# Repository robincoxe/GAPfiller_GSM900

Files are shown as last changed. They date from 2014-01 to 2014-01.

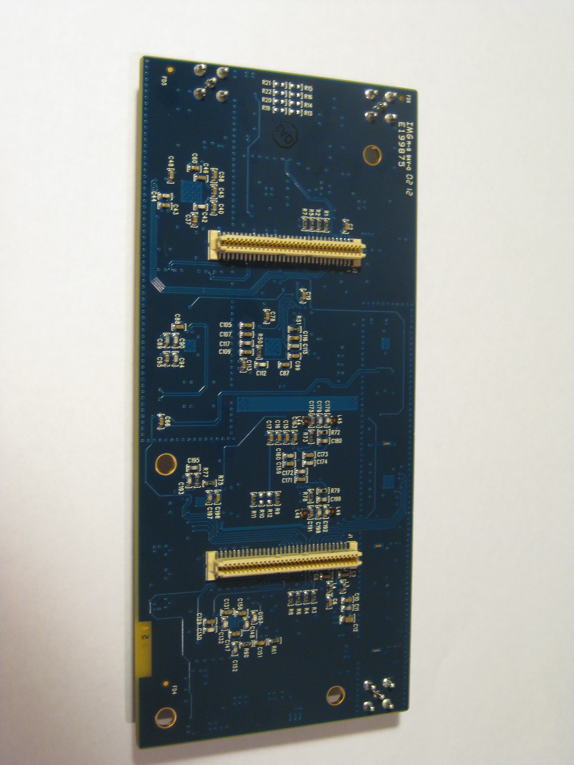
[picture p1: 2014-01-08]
docs/GAPfiller_GSM900_bottom.jpg

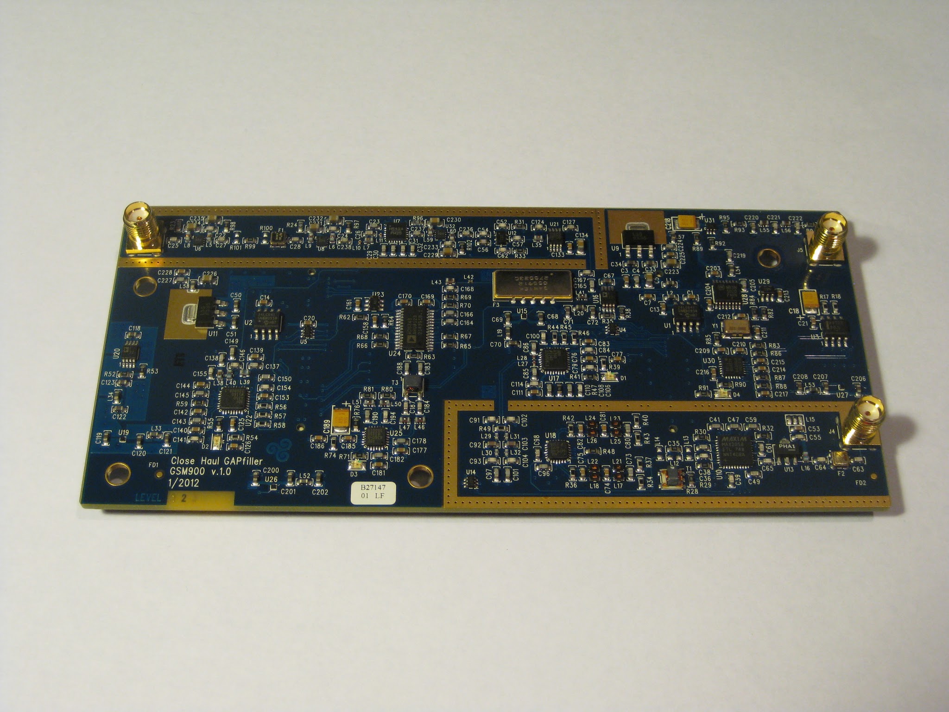
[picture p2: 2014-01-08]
docs/GAPfiller_GSM900_top.jpg

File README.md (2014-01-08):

# GAPfiller GSM900 Version 3 #

Copyright 2014, Close-Haul Communications, Inc.

### Revision History ###

7 January 2014: First commit of OrCAD schematics, PADS PCB layout, Gerber files

### README ###

The GAPfiller GSM900 version 3.0 board is a RF front end daughtercard intended for a single TRX GSM basestation in the 900 MHz band.  The GAPfiller GSM900 is compatible with the [Ettus Research](https://www.ettus.com/product) USRP software-defined radio systems. 

Modifications to the USRP FPGA and UHD are necessary to run OpenBTS or osmo-bts on the GAPfiller board.  As this work is completed, these modifications will be added to this repository on Github.
 
This design is open source hardware released under the [CERN Open Hardware Licence v1.2](http://www.ohwr.org/licenses/cern-ohl/v1.2).

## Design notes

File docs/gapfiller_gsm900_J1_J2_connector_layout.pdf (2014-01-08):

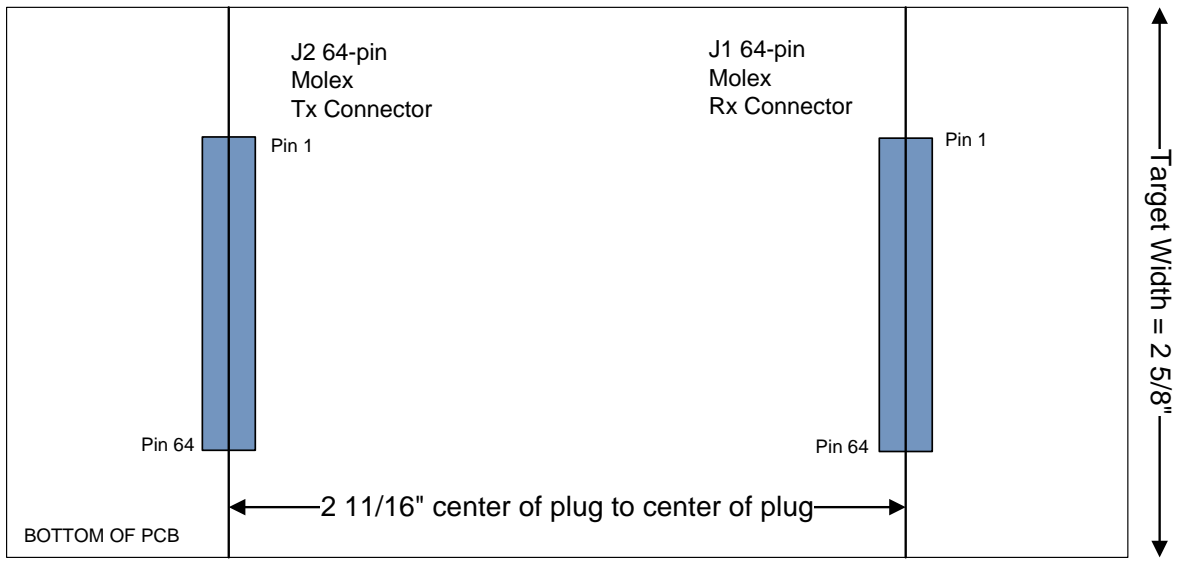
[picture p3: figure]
BOTTOM OF PCB; J2 64-pin Molex Tx Connector; J1 64-pin Molex Rx Connector; Pin 1; Target Width = 2 5/8"; Pin 64

GAPfiller GSM900
Daughterboard Connector Layout Close-Haul Communications, Inc.
October 2011

Copyright 2011 Close-Haul Communications, Inc. All Rights Reserved

NOT TO SCALE!

2 11/16" center of plug to center of plug

Target Length = 5 ¾”

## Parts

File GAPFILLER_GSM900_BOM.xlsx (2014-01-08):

 |  | Close-Haul Communications Inc. GAPfiller_GSM900 Revision: 2
 |  | Bill Of Materials 7 Feb 2013
Item # | Quantity | Reference | Part | Footprint | Description | Manufacturer | Mfg. Part # | Vendor | Customer Supplied Qty.
1 | 66 | C1,C2,C3,C6,C7,C8,C9,C10,C13,C14,C15,C16,C17,C19,C20, C21,C40,C43,C45,C48,C53,C58,C66,C78,C83,C87,C88,C95, C99,C105,C107,C109,C111,C113,C129,C131,C139, C140,C142,C144,C147,C153,C156,C158,C159,C161,C163, C169,C170,C171,C173,C177,C181,C196,C203,C209,C210, C211,C212,C213,C214,C215,C216,C217,C225,C228 | 0.1 uF | IPC_0603 | CAP CERAMIC 0603 X7R .1UF 10% 50V | Cal-Chip | GMC10X7R104K50NT-LF | Cal-Chip
2 | 26 | C4,C11,C23,C41,C47,C59,C89,C96,C97,C101,C108,C110, C143,C145,C164,C166,C178,C182,C183,C188,C190,C197, C205,C219,C224,C227 | 1 nF | IPC_0603 | CAP CER 1000PF 5% 50V NP0 0603 | AVX | 06035A102JAT2A | Digikey
3 | 11 | C5,C12, C134, C223,C226,C229,C230,C231,C232,C234,C235 | 4.7 uF | IPC_0805 | CAP CER 4.7UF 16V X5R 0805 | Murata | GRM21BR61C475KA88L | Digikey
4 | 3 | C18,C189,C218 | 10 uF | IPC_1210 | CAP TANTALUM 10UF 16V 10% SMD | Kemet | B45190E3106K209 | Digikey
5 | 21 | C36,C39,C42,C54,C57,C63,C64,C65,C79,C84,C100,C106, C112,C114,C130,C132,C141,C148,C154,C157,C168 | 47 pF | IPC_0603 | CAP0603 COG 47PF 5% 50V | Kemet | IPC_0603C470J5GACTU | Newark
6 | 1 | C26 | 8 pF | IPC_0603 | CAP0603 COG 8 PF 0.5PF 50V | Multicomp | MIPC_0603N8R0D500CT | Newark
7 | 25 | C25,C27,C28,C29,C30,C31,C32,C38,C44,C49,C61,C90,C94, C98,C127,C160,C172,C174,C184,C187,C236,C237,C238, C239,C240 | 100 pF | IPC_0603 | CAP0603 COG 100PF 5% 50V | AVX | 06035A101JAT2A | Newark
8 | 22 | C33,C34,C50,C51,C67,C68,C69,C70,C71,C72,C118,C119, C120,C121,C122,C123,C200,C201,C202,C206,C207,C208 | 1 uF | IPC_0603 | CAP CERAMIC 1.00UF 16V X5R 0603 | Kemet | IPC_0603C105K4PACTU | Digikey
9 | 9 | C35,R83,R85,R86,R87,R88,R94,R99,R103 | 0 | IPC_0603 | RES 0.0 1/10W 5% 0603 | Vishay | CRCW06030000Z0EA | Arrow
10 | 10 | C37,C60,C76,C77,C125,C126,C133,C185,C186,C204 | 0.01 uF | IPC_0603 | CAP CER 10000PF 50V X7R 0603 | Kemet | IPC_0603C103J5RACTU | Digikey
11 | 1 | C46 | 3.9 pF | IPC_0603 | CAP0603 COG 4PF 5% 50V | TDK | C1608C0G1H040B | Newark
12 | 3 | C52,C55,C62 | 22 pF | IPC_0603 | CAP0603 COG 22PF 5% 50V | Kemet | IPC_0603C220J5GACTU | Newark
13 | 1 | C56 | 150 pF | IPC_0603 | CAP0603 COG 150PF 5% 50V | AVX | 06035A151JAT2A | Newark
14 | 2 | C73,C80 | 1.4 nF | IPC_0603 | CAP0603 COG 1500PF 5% 50V | TDK | C1608C0G1H152J | Newark
15 | 2 | C74,C81 | 6.4 nF | IPC_0603 | CAP0603 X7R 6800PF 10% 50V | Kemet | IPC_0603C682K5RACTU | Newark
16 | 2 | C75,C82 | 18 nF | IPC_0603 | CAP CER 0603 0.018UF 25V X7R | Multicomp | MIPC_0603B183K250CT | Newark
17 | 5 | C85,C86,C137,C138,C221 | 120 pF | IPC_0603 | CAP CER 120PF 50V 5% C0G 0603 | AVX | 06035A121JAT2A | Newark
18 | 5 | C91,C93,C102,C104,C124 | 3.3 pF | IPC_0603 | CAP0603 COG 3.3PF 5% 50V | Multicomp | MC0603N3R3C210CT | Newark
19 | 2 | C92,C103 | 4.7 pF | IPC_0603 | CAP0603 COG 4.7PF 5% 50V | Multicomp | MC0603N4R7C210CT | Newark
20 | 2 | C115,C150 | 2700 pF | IPC_0603 | CAP CER 2700PF 50V C0G 0603 | Murata | GRM1885C1H272JA01D | Digikey
21 | 2 | C116,C151 | 39 nF | IPC_0603 | CAP CER X7R 0.039UF 10% 16V 0603 | Multicomp | MIPC_0603B393K160CT | Newark
22 | 2 | C117,C152 | 1200 pF | IPC_0603 | CAP CER 1200PF 50V 5% C0G 0603 | Murata | GRM1885C1H122JA01D | Digikey
23 | 2 | C146,C155 | 2.2 pF | IPC_0603 | CAP0603 COG 2.2PF 5% 50V | Multicomp | MC0603N2R2C210CT | Cal-Chip
24 | 1 | C149 | 10 pF | IPC_0603 | CAP0603 COG 10PF 5% 50V | Cal-Chip | GMC10CG100J50NT-LF | Cal-Chip
25 | 1 | C165 | 7 pF | IPC_0603 | CAP0604 COG 7PF 5% 50V | Multicomp | MC0603N7R0C210CT | Newark
26 | 4 | C22,C24,C167,C233 | 33 pF | IPC_0603 | CAP0603 COG 33PF 5% 50V | Cal-Chip | GMC10CG330J50NT-LF | Cal-Chip
27 | 3 | C175,C191 | 8.2 pF | IPC_0603 | CAP0603 COG 8.2PF 5% 50V | Cal-Chip | GMC10CG8R2J50NT-LF | Cal-Chip
28 | 2 | C176,C192 | 14.2 pF | IPC_0603 | CAP0603 COG 15PF 5% 50V | AVX | 06035A150JAT2A | Newark
29 | 2 | C179,C198 | 260 pF | IPC_0603 | CAP0603 COG 270PF 5% 50V | AVX | 06035A271JAT2A | Newark
30 | 2 | C180,C199 | 142 pF | IPC_0603 | CAP0603 COG 150PF 5% 50V | AVX | 06035A151JAT2A | Newark
31 | 1 | C193 | 122 pF | IPC_0603 | CAP0603 COC 120PF 5% 50V | AVX | 06035A121JAT2A | Newark
32 | 1 | C194 | 56 pF | IPC_0603 | CAP0603 COG 56PF 5% 50V | Cal-Chip | GMC10CG560J50NT-LF | Cal-Chip
33 | 1 | C195 | 1.6 nF | IPC_0603 | CAP CER 1600PF 50V 5% C0G 0603 | Murata | GRM1885C1H162JA01D | Digikey
34 | 1 | C220 | 68 pF | IPC_0603 | CAP0603 COG 68PF 5% 50V | Cal-Chip | GMC10CG680J50NT-LF | Cal-Chip
35 | 1 | C222 | 82 pF | IPC_0603 | CAP0603 COG 82PF 5% 50V | Cal-Chip | GMC10CG820J50NT-LF | Cal-Chip
36 | 1 | D1,D2,D3,D4 | GREEN_LED | IPC_0805 | LED GREEN CLEAR THIN 0805 SMD | Lite-On | LTST-C171GKT | Digikey
37 | 1 | F1 | 856671 | SM3x3x1p22mm | 897.5 MHz SAW Filter | Triquint | 856671 | Verical
38 | 1 | F2 | 855810 | SM3x3x1p22mm | 942.5 MHz SAW Filter | Triquint | 855810 | Verical | 50 (please return excess)
39 | 1 | F3 | 856347 | 855912 | 170.6 MHz GSM IF SAW filter | Triquint | 856347 | Verical | 50 (please return excess)
40 | 2 | J1,J2 | 71439-0164 | 64PIN_71439 | Molex 64 pin plug connectors | Molex | 71439-0164 | Digikey
41 | 3 | J3,J4,J5 | SMA-SMD | SMA-SMD | SMA connector, straight PCB | Amphenol | 901-144-8RFX | Digikey
42 | 7 | L1,L3,L20,L34,L54,L57,L58 | ferrite_0603 1000ma | IPC_0603 | FERRITE CHIP POWER 1000 mA 600 OHM SMD | Steward | MI0603J601R-10 | Digikey
43 | 6 | L2,L4,L19,L33,L52,L53 | ferrite_0603 200ma | IPC_0603 | FERRITE 200MA 1000 OHM 0603 SMD | Steward | HZ0603B102R-10 | Digikey
44 | 2 | L7,L35 | 10 nH | IPC_0603 | IND0603CS 10NH | Coilcraft | 0603CS-10NXJLU | Coilcraft
45 | 2 | L10,L11 | 7 nH | IPC_0302 | IND0302CS 7NH | Coilcraft | 0302CS-7N0XJLU | Coilcraft
46 | 5 | L12,L13,L14,R100,R101 | DNI | IPC_0603
47 | 1 | L15 | NFM21P | IPC_0805 | FILTER LC HIGH FREQ .47UF 0805 | Murata | NFM21PC474R1C3D | Digikey
48 | 1 | L16 | 18 nH | IPC_0603 | IND0603CS 18NH | Coilcraft | 0603CS-18NXJLU | Coilcraft
49 | 6 | L5,L6,L8,L9,L59,L60 | 33 nh | IPC_0603 | IND0603CS 33NH | Coilcraft | 0603CS-33NXJLU | Coilcraft
50 | 4 | L17,L21,L23,L25 | 10 uH | IPC_0603 | IND0603LS 10UH | Coilcraft | 0603LS-103XJLU | Coilcraft
51 | 4 | L18,L22,L24,L26 | 22 uH | IPC_0603 | IND0603LS 22UH | Coilcraft | 0603LS-223XJLU | Coilcraft
52 | 2 | L27,L28 | 19 nH | IPC_0302 | IND0302CS 19NH | Coilcraft | 0302CS-19NXJLU | Coilcraft
53 | 4 | L29,L30,L31,L32 | 2.7 nH | IPC_0402 | IND0402CS 2.7NH | Coilcraft | 0402CS-2N7XJLU | Coilcraft
54 | 1 | L38 | 39 nH | IPC_0603 | IND0603CS 39NH | Coilcraft | 0603CS-39NXJLU | Coilcraft
55 | 2 | L39,L40 | 12 nH | IPC_0603 | IND0603CS 12NH | Coilcraft | 0603CS-12NXJLU | Coilcraft
56 | 1 | L41 | 150 nH | IPC_0603 | IND0603HP 150NH | Coilcraft | 0603HP-R15XJLU | Coilcraft
57 | 1 | L42 | 4 nH | IPC_0302 | IND0302CS 4NH | Coilcraft | 0302CS-4N0XJLU | Coilcraft
58 | 1 | L43 | 47 nH | IPC_0603 | IND0603CS 47NH | Coilcraft | 0603CS-47NXJLU | Coilcraft
59 | 2 | L44,L48 | 1.2 uH | IPC_0603 | IND0603LS 1.2UH | Coilcraft | 0603LS-122XJLU | Coilcraft
60 | 2 | L45,L49 | 2.1 uH | IPC_0603 | IND0603LS 2.2UH | Coilcraft | 0603LS-222XJLU | Coilcraft
61 | 2 | L46,L47 | 148 nH | IPC_0603 | IND0603HP 150NH | Coilcraft | 0603HP-R15XJLU | Coilcraft
62 | 2 | L50,L51 | 94.7 nH | IPC_0603 | IND0603HP 91NH | Coilcraft | 0603HP-91NXJLU | Coilcraft
63 | 2 | L55,L56 | 220 nH | IPC_0603 | IND0603HP 220NH | Coilcraft | 0603HP-R22XJLU | Coilcraft
64 | 12 | R1,R2,R3,R4,R5,R6,R7,R8,R31,R33,R48,R91 | 330 | IPC_0603 | RES 330 1/10W 5% 0603 | Vishay/Dale | CRCW0603330RFKEA | Arrow
65 | 2 | R9,R11 | 2.49K | IPC_0603 | RES 2.49K 1/10W 5% 0603 | Vishay/Dale | CRCW06032K49FKEA | Arrow
66 | 10 | R10,R12,R13,R14,R15,R16,R19,R20,R21,R22 | DNI | IPC_0603
67 | 2 | R17,R18 | 33 | IPC_0603 | RES 33 1/10W 5% 0603 | Vishay/Dale | CRCW060333R0FKEA | Arrow
68 | 1 | R28 | 110 | IPC_0603 | RES 110 1/10W 5% 0603 | Vishay/Dale | CRCW0603110RFKEA | Arrow
69 | 2 | R29,R62 | 2K | IPC_0603 | RES 2K 1/10W 5% 0603 | Vishay/Dale | CRCW06032K00FKEA | Arrow
70 | 1 | R30 | 1.2K | IPC_0603 | RES 1.2K 1/10W 5% 0603 | Vishay/Dale | CRCW06031K20FKEA | Arrow
71 | 1 | R32 | 3.92K | IPC_0603 | RES 3.92K 1/10W 5% 0603 | Vishay/Dale | CRCW06033K92FKEA | Arrow
72 | 3 | R23,R24,R96 | 6.8K | IPC_0603 | RES 6.8K 1/10W 5% 0603 | Vishay/Dale | CRCW06068K92FKEA
73 | 3 | R97,R98,R102 | 8.2 | IPC_0603 | RES 8.2 1/10W 5% 0603 | Vishay/Dale | CRCW060308R0FKEA
74 | 7 | R34,R37,R39,R40,R43,R54,R74 | 49.9 | IPC_0603 | RES 49.9 1/10W 5% 0603 | Vishay/Dale | CRCW060349R9FKEA | Arrow
75 | 2 | R35,R52 | 210K | IPC_0603 | RES 210K 1/10W 5% 0603 | Vishay/Dale | CRCW0603210KFKEA | Arrow
76 | 5 | R36,R42,R49,R72,R79 | 100 | IPC_0603 | RES 100 1/10W 5% 0603 | Vishay/Dale | CRCW0603100RFKEA | Arrow
77 | 2 | R38,R53 | 64.9K | IPC_0603 | RES 64.9K 1/10W 5% 0603 | Vishay/Dale | CRCW060364K9FKEA | Arrow
78 | 6 | R41,R55,R71,R82,R84,R90 | 1K | IPC_0603 | RES 1K 1/10W 5% 0603 | Vishay/Dale | CRCW06031K00FKEA | Arrow
79 | 6 | R44,R45,R46,R56,R57,R58 | 10K | IPC_0603 | RES 10K 1/10W 5% 0603 | Vishay/Dale | CRCW060310K0FKEA | Arrow
80 | 4 | R47,R59,R76,R95 | 4.7K | IPC_0603 | RES 4.7K 1/10W 5% 0603 | Vishay/Dale | CRCW06034K70FKEA | Arrow
81 | 2 | R50,R60 | 680 | IPC_0603 | RES 680 1/10W 5% 0603 | Vishay/Dale | CRCW0603680RFKEA | Arrow
82 | 2 | R51,R61 | 360 | IPC_0603 | RES 360 1/10W 5% 0603 | Vishay/Dale | CRCW0603360RFKEA | Arrow
83 | 1 | R63 | 60.4 | IPC_0603 | RES 60.4 1/10W 5% 0603 | Vishay/Dale | CRCW060360R4FKEA | Arrow
84 | 1 | R64 | 1.1K | IPC_0603 | RES 1.1K 1/10W 5% 0603 | Vishay/Dale | CRCW06031K10FKEA | Arrow
85 | 4 | R65,R66,R67,R68 | 200 | IPC_0603 | RES 200/10W 5% 0603 | Vishay/Dale | CRCW0603200RFKEA | Arrow
86 | 1 | R69 | 57.6 | IPC_0603 | RES 57.6 1/10W 5% 0603 | Vishay/Dale | CRCW060357R6FKEA | Arrow
87 | 1 | R70 | 174 | IPC_0603 | RES174 1/10W 5% 0603 | Vishay/Dale | CRCW0603174RFKEA | Arrow
88 | 2 | R73,R78 | 60 | IPC_0603 | RES 60 1/10W 5% 0603 | Vishay/Dale | CRCW060360R4FKEA | Arrow
89 | 1 | R75 | 27.5K | IPC_0603 | RES 27.4K 1/10W 5% 0603 | Vishay/Dale | CRCW060327K4FKEA | Arrow
90 | 1 | R77 | 13.5K | IPC_0603 | RES 13.7K 1/10W 5% 0603 | Vishay/Dale | CRCW060313K7FKEA | Arrow
91 | 2 | R80,R81 | 470 | IPC_0603 | RES 470 1/10W 5% 0603 | Vishay/Dale | CRCW0603470RFKEA | Arrow
92 | 2 | R89,R93 | 10 | IPC_0603 | RES 10 1/10W 5% 0603 | Vishay/Dale | CRCW060310R0FKEA | Arrow
93 | 1 | R92 | 2.2K | IPC_0603 | RES 2.2K 1/10W 5% 0603 | Vishay/Dale | CRCW06032K20FKEA | Arrow
94 | 1 | T1 | TC2-1T | AT224 | RF Transformer 2:1 3-300 MHz 50 Ohm | Mini-Circuits | TC2-1TG2+ | Mini-Circuits
95 | 1 | T3 | ETC1-1-13 | SM-22 | E-Series RF 1:1 Transmission Line Transformer 4.5-3000 MHz | M/A-Com | ETC1-1-13 | Avnet
96 | 2 | U1,U2 | 24LC64-I/SN | 8-SOIC-SN | 64K I2C Serial EEPROM | Microchip | 24LC64-I/SN | Digikey
97 | 1 | U3 | MC100LVELT23DG | SOIC-8-NB | 3.3 V Dual Differential LVPECL/LVDS to LVTTL Translator | OnSemi | MCLEVLT23DGOS | Digikey
98 | 3 | U4,U5,U14 | NC7WZ04P6X | SC-70 | UHS Dual Inverter | Fairchild | NC7WZ04P6X | Digikey
99 | 1 | U7 | HMC542ALP4E | QFN-24-HMC | 0.5 dB LSB 6-Bit Digital Attenuator Serial Control DC-4 GHz | Hittite | HMC542ALP4E | Hittite
100 | 2 | U9,U11 | ADP3339AKCZ-5 | KC-3 | High Accuracy 1.5 A Low Dropout Regulator 5VDC | ADI | ADP3339AKCZ-5-R7
101 | 1 | U10 | MAX2058 | T4066-3 | 700-1200 MHz DVGA w/Integrated Loopback Mixer | Maxim | MAX2058ETL+ | Digikey
102 | 1 | U12 | AS225-313LF | QFN-6 | PHEMT GaAs IC 1 W Low Loss 0.1-6 GHz SPDT Switch | Skyworks | AS225-313LF | Digikey
103 | 1 | U13 | PHA-1+ | SOT-89 | UHD Monolithic Amplifier 0.05-6 GHz 50 ohm | Mini-Circuits | PHA-1+ | Mini-Circuits
104 | 3 | U6,U8,U32 | MGA-633P8 | QFN-8-2x2x0p75 | Ultralow Noise, High Linearity Active Bias LNA | Avago | MGA-633P8 | Digikey
105 | 4 | U15,U19,U26,U27 | ADP150-AUJZ-3.3 | UJ-5 (TSOP 5 PIN) | Ultralow Noise, 150 mA CMOS Linear Regulator 3.3VDC | ADI | ADP150-ACBZ-3.3
106 | 2 | U16,U20 | ADP3336AR | RN-8 | High Accuracy 500 mA Adjustable Low Dropout Regulator | ADI | ADP3336ARMZ-REEL7
107 | 2 | U17,U22 | ADF4350 | CP-32-2 | Wideband Synthesizer with Integrated VCO | ADI | ADF4350BCPZ
108 | 1 | U18 | ADL5375 | CP-24-3 | 400 MHz-6 GHz Broadband Quadrature Modulator | ADI | ADL5375-05ACPZ-WP
109 | 1 | U21 | HMC483MS8GE | MSOP-8 | High IP3 GaAs MMIC Mixer with Integrated LO amplifier, 0.7-1.5 GHz | Hittite | HMC483MS8GE
110 | 2 | U23,U29 | AD5320 | RT-6 | 2.7 V to 5.5 V, 140 μA, Rail-to-Rail Output 12-Bit DAC | ADI | AD5320BRTZ-500RL7
111 | 1 | U24 | AD8348 | RU-28 | 50-1000 MHz Quadrature Demodulator | ADI | AD8348ARUZ
112 | 1 | U25 | ADF4360-8 | CP-24-1 | 65-400 MHz Integrated Synthesizer and VCO | ADI | ADF4360-8BCPZ
113 | 1 | U28 | NB3N3020DTG | TSSOP-16 | 3.3V LVPECL/LVCMOS clock multipler | OnSemi | NB3N3020DTG | Mouser
114 | 1 | U30 | Si5330K-A00224-GM | QFN-24-SI | Low Jitter, Low Skew Clock Buffer/Level Translator, Single ended input, 3.3V LVPECL 5-350 MHz | Silicon Labs | Si5330K-A00224-GM | Mouser | 5
115 | 1 | U31 | SN74LVC1GU04DCKR | DCK5 | Single Inverter Gate | TI | SN74LVC1GU04DCKR | Digikey
116 | 1 | Y1 | TCD4029-26.0M | LCC-8 | Microcell/Femtocell 26.0 MHz TCVCXO Oscillator | Pletronics | TCD4029-26.0M | Pletronics
 |  | Line items in YELLOW will be supplied by the customer.

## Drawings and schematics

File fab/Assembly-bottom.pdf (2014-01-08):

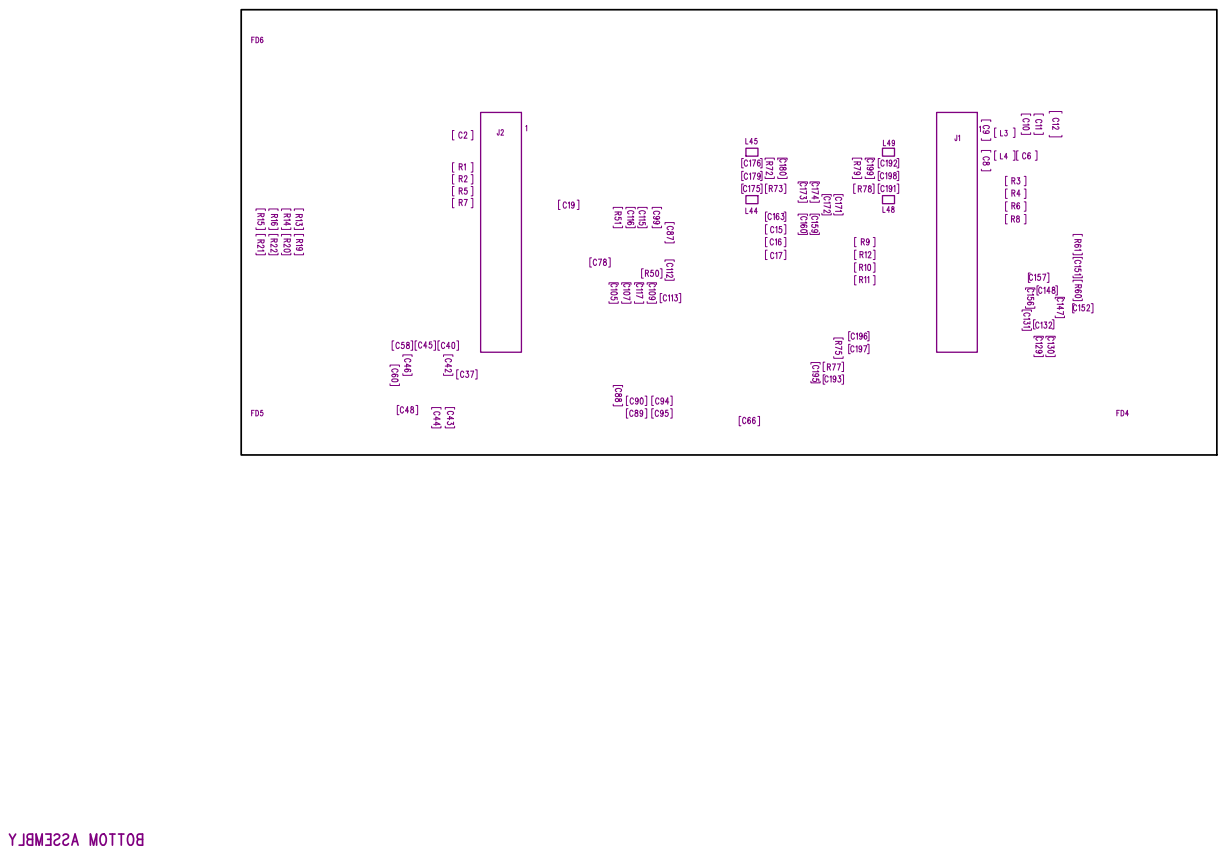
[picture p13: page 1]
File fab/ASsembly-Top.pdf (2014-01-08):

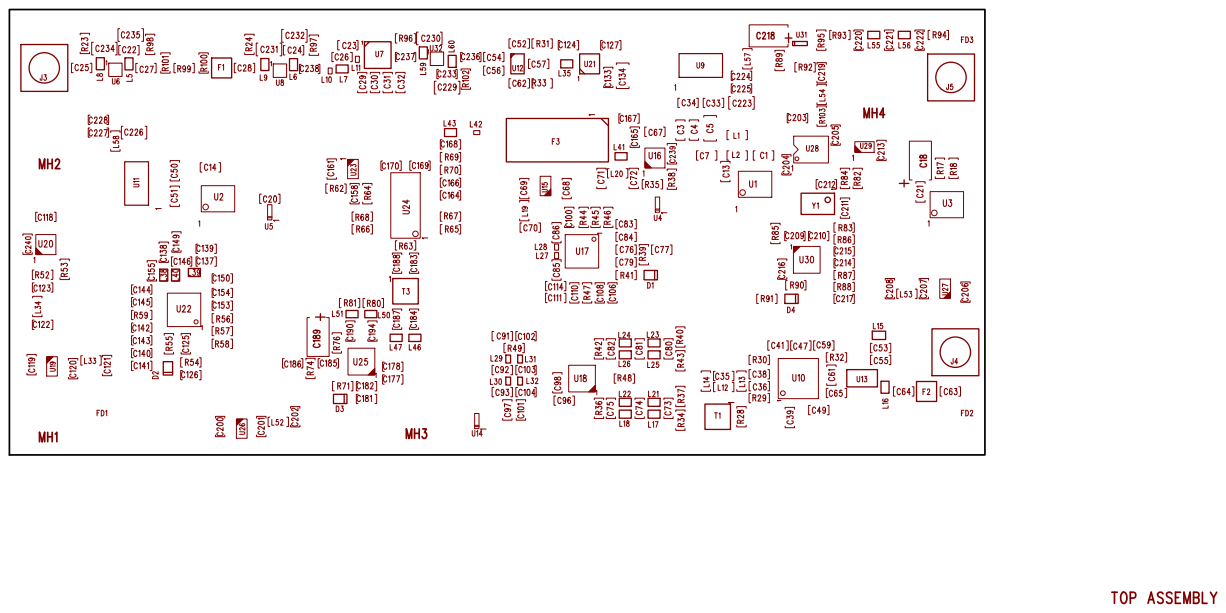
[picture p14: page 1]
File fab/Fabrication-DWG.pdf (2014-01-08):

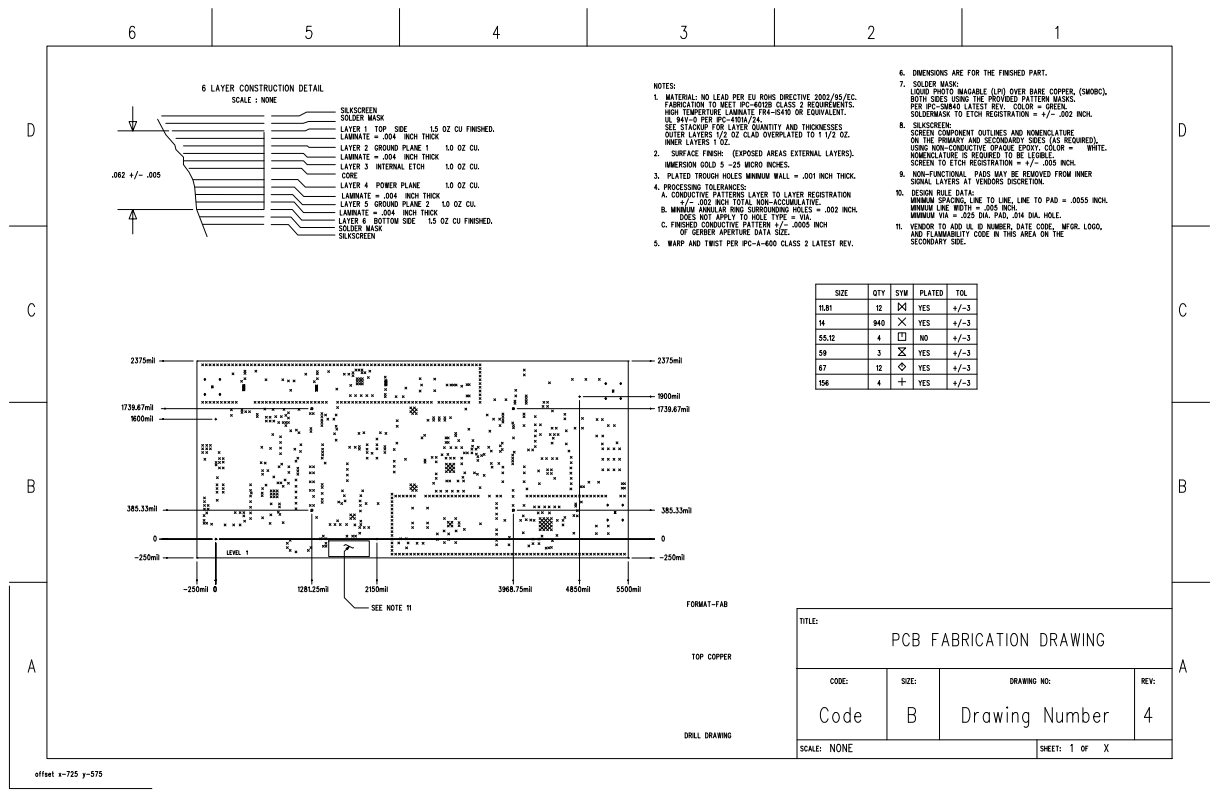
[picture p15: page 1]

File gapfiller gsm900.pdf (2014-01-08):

# GAPfiller GSM900 RF Daughterboard Version 3.0

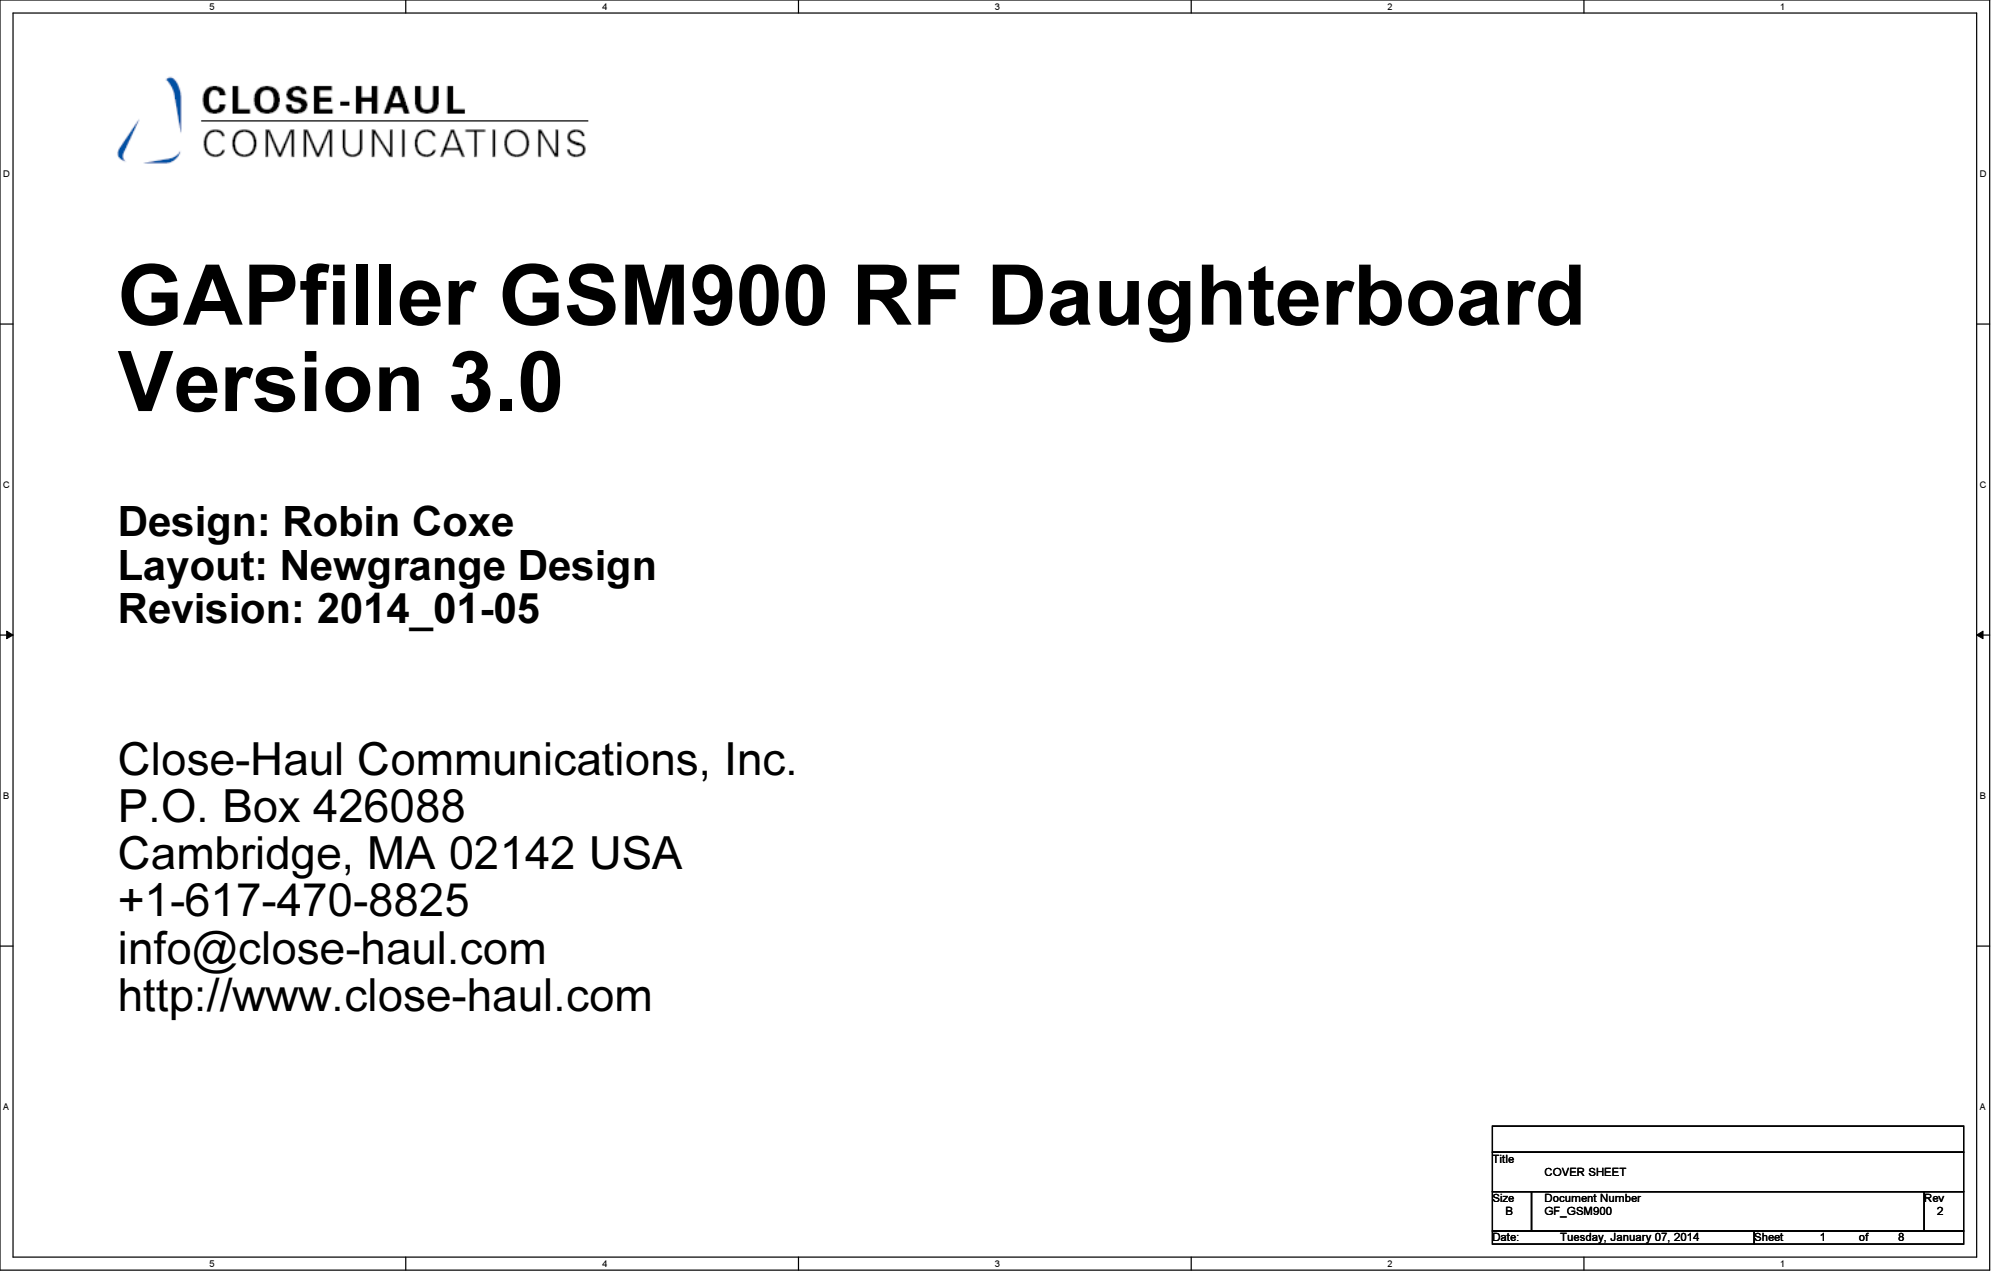
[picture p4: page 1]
Title; Size; Document Number; Rev; Date:; Sheet; GF_GSM900; COVER SHEET; Tuesday, January 07, 2014

Design: Robin Coxe
Layout: Newgrange Design
Revision: 2014_01-05

Close-Haul Communications, Inc.
P.O. Box 426088
Cambridge, MA 02142 USA
info@close-haul.com
http://www.close-haul.com

## J1 and J2 Spacing: 2 11/16" from center to center

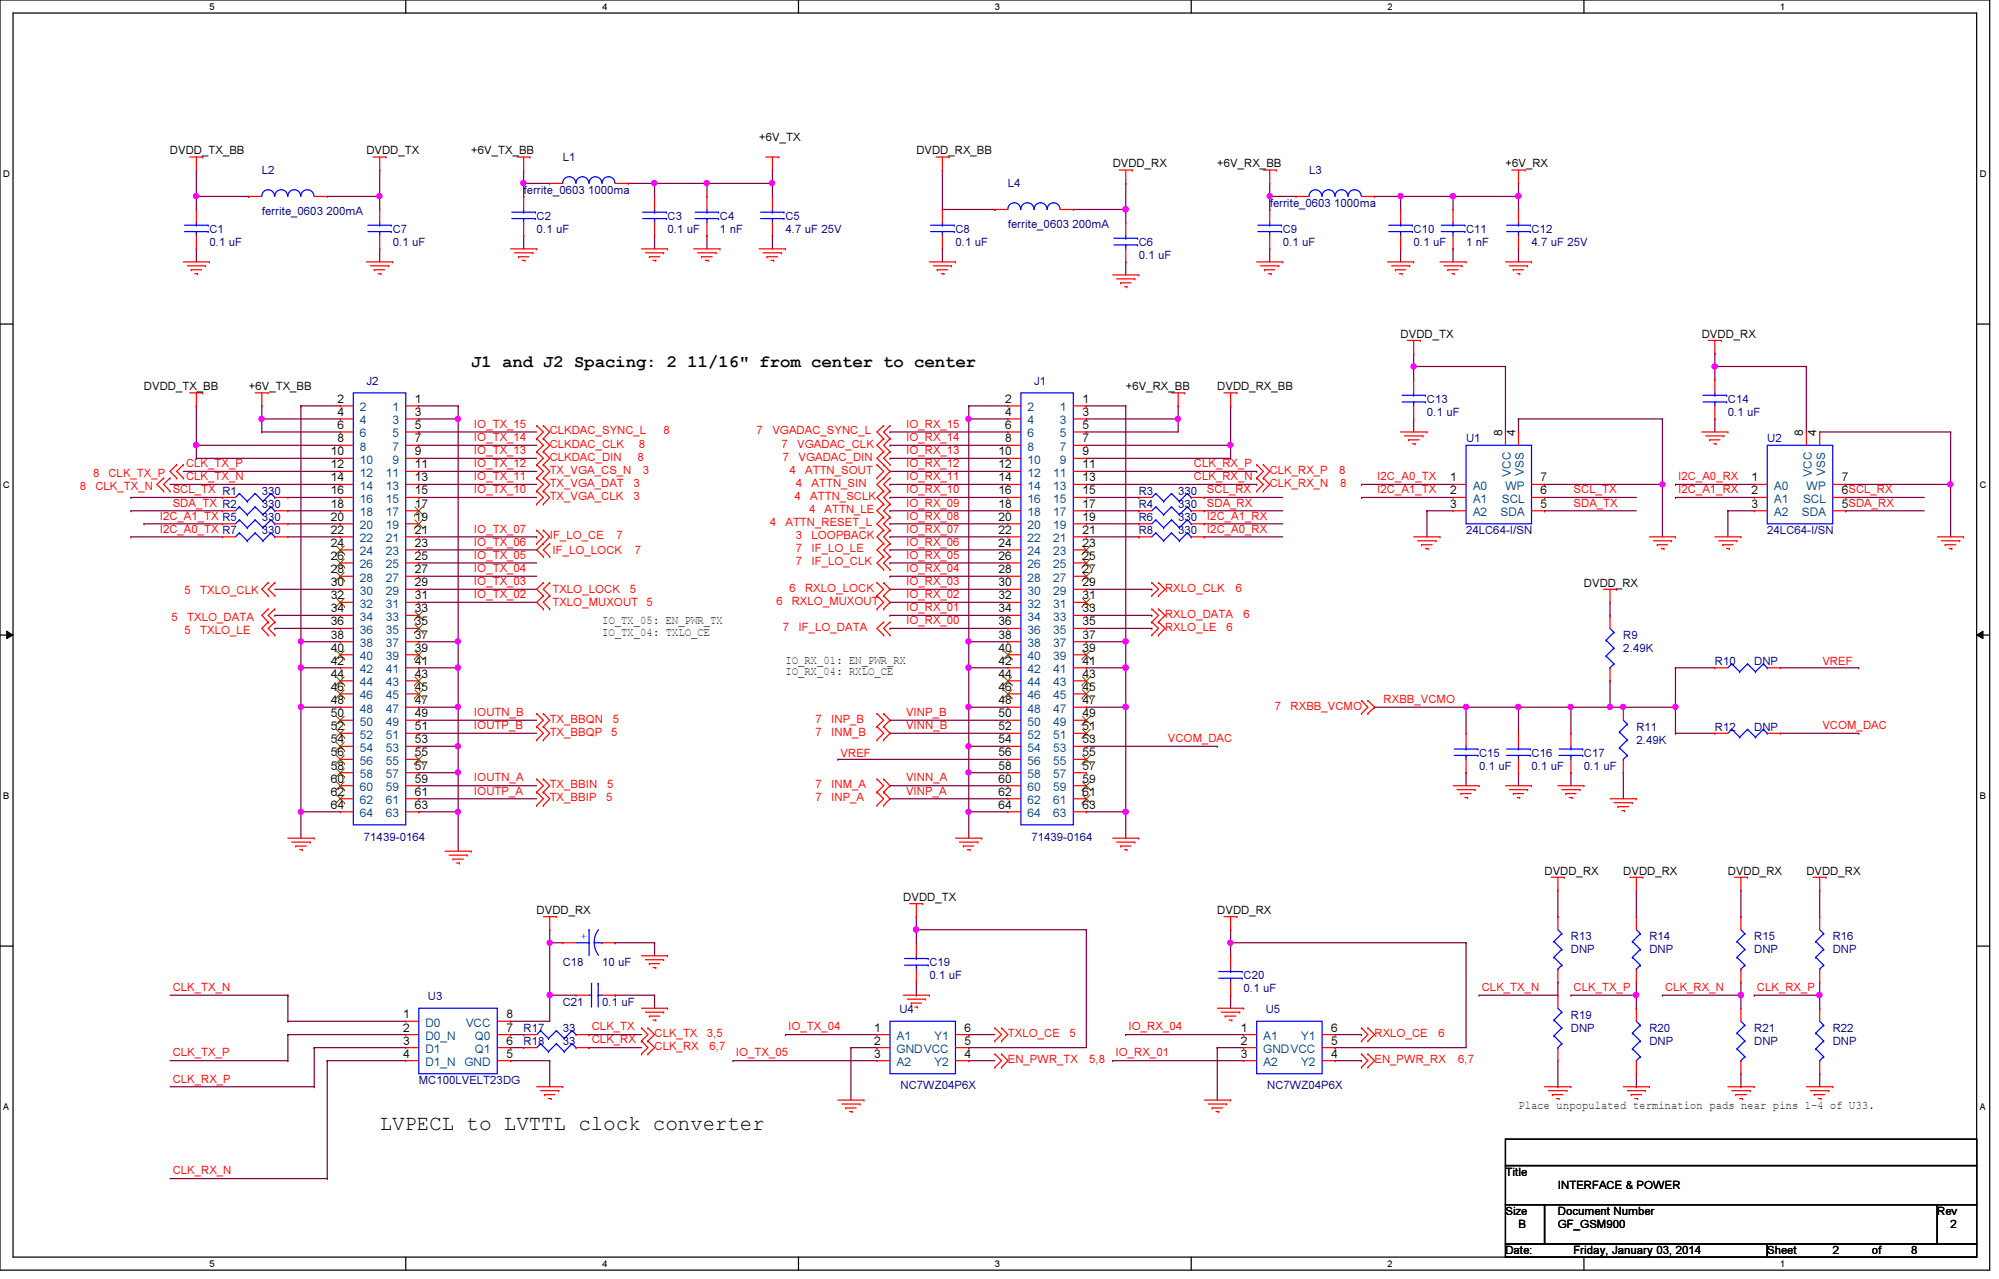
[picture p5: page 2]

Place unpopulated termination pads near pins 1-4 of U33.

LVPECL to LVTTL clock converter

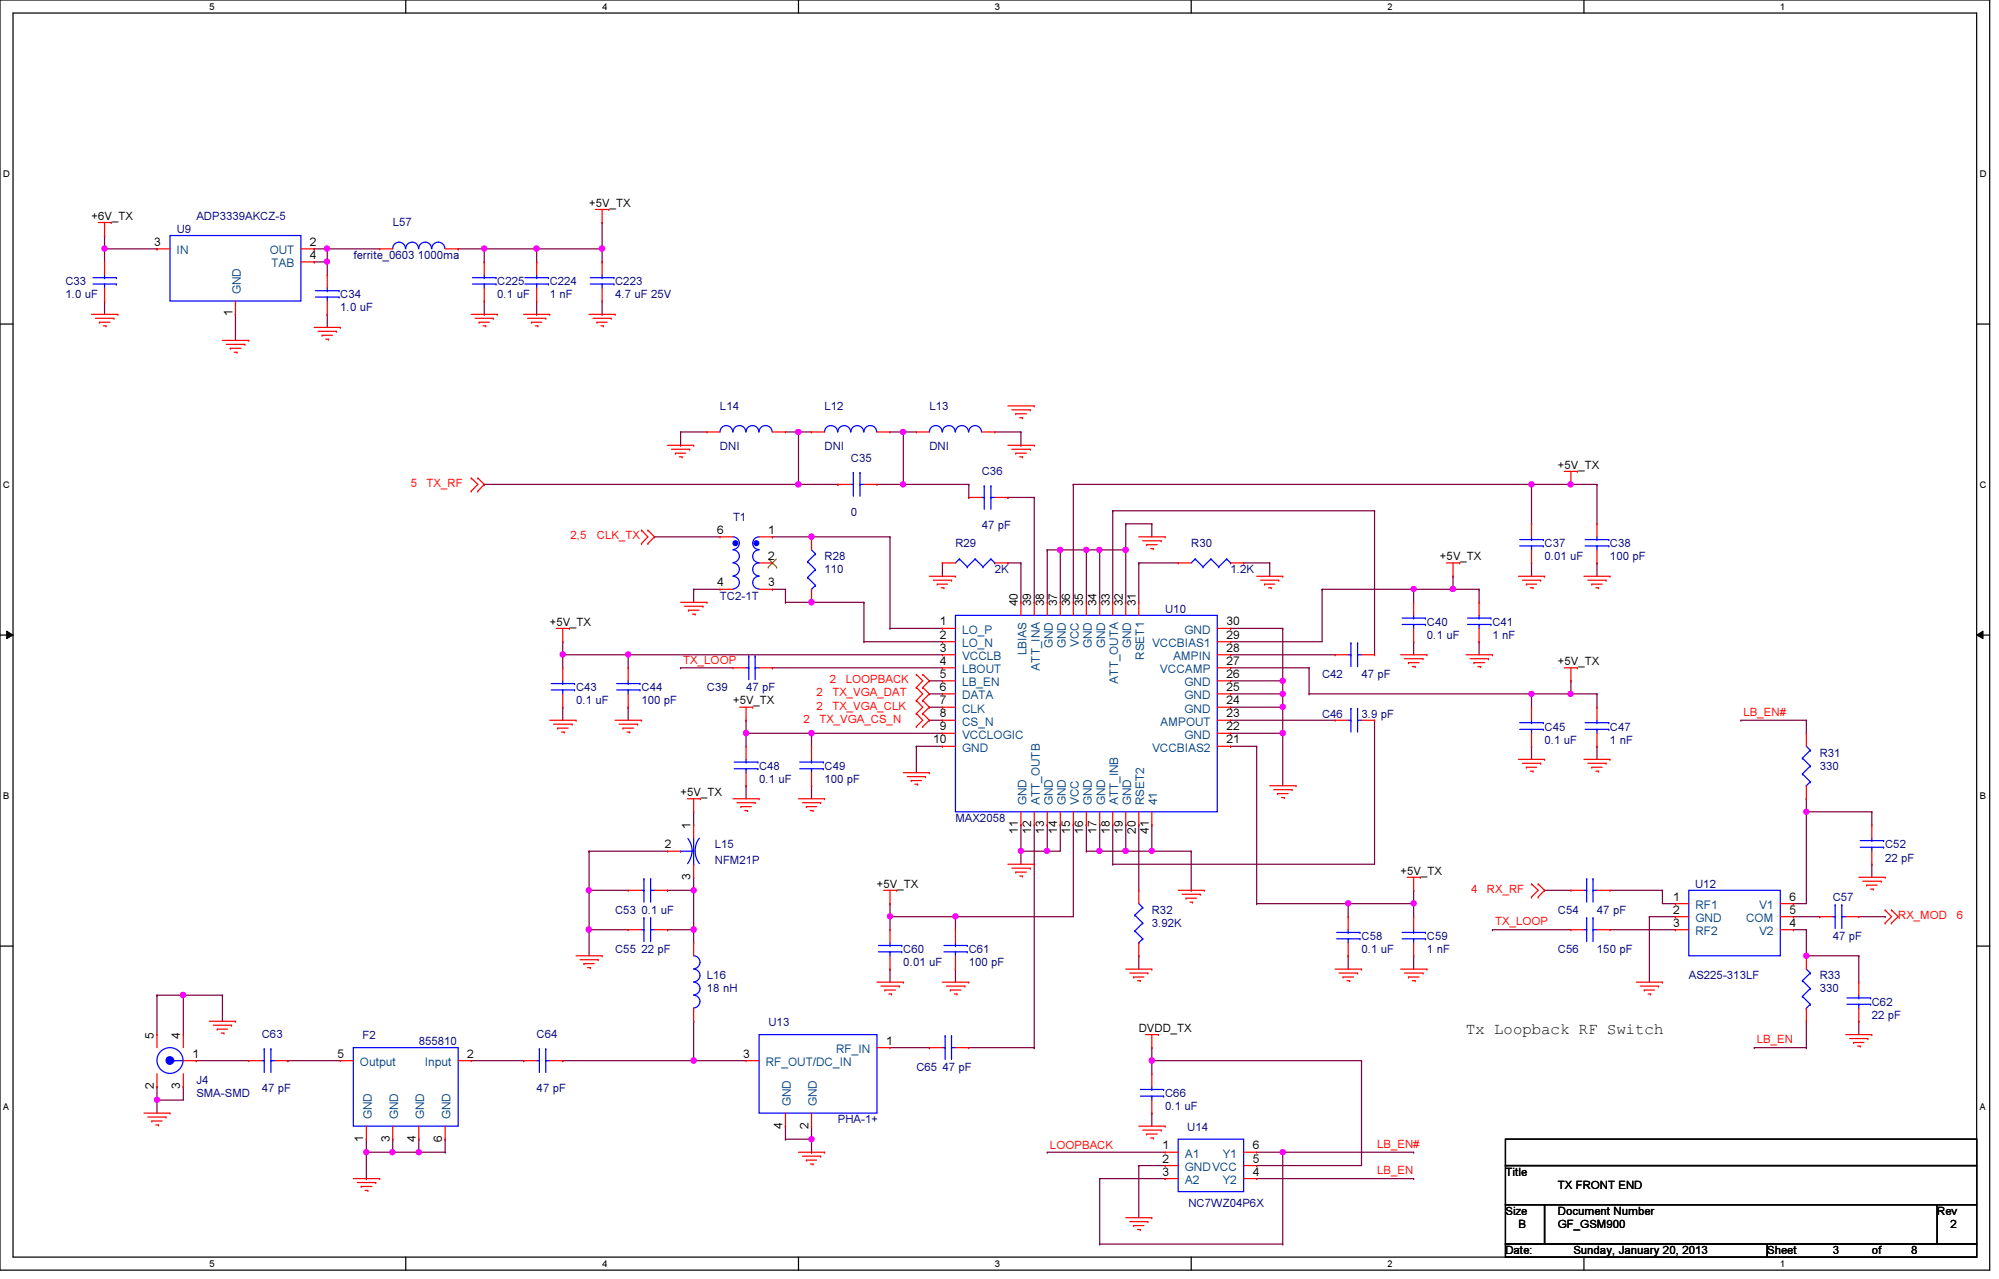
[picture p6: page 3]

Tx Loopback RF Switch

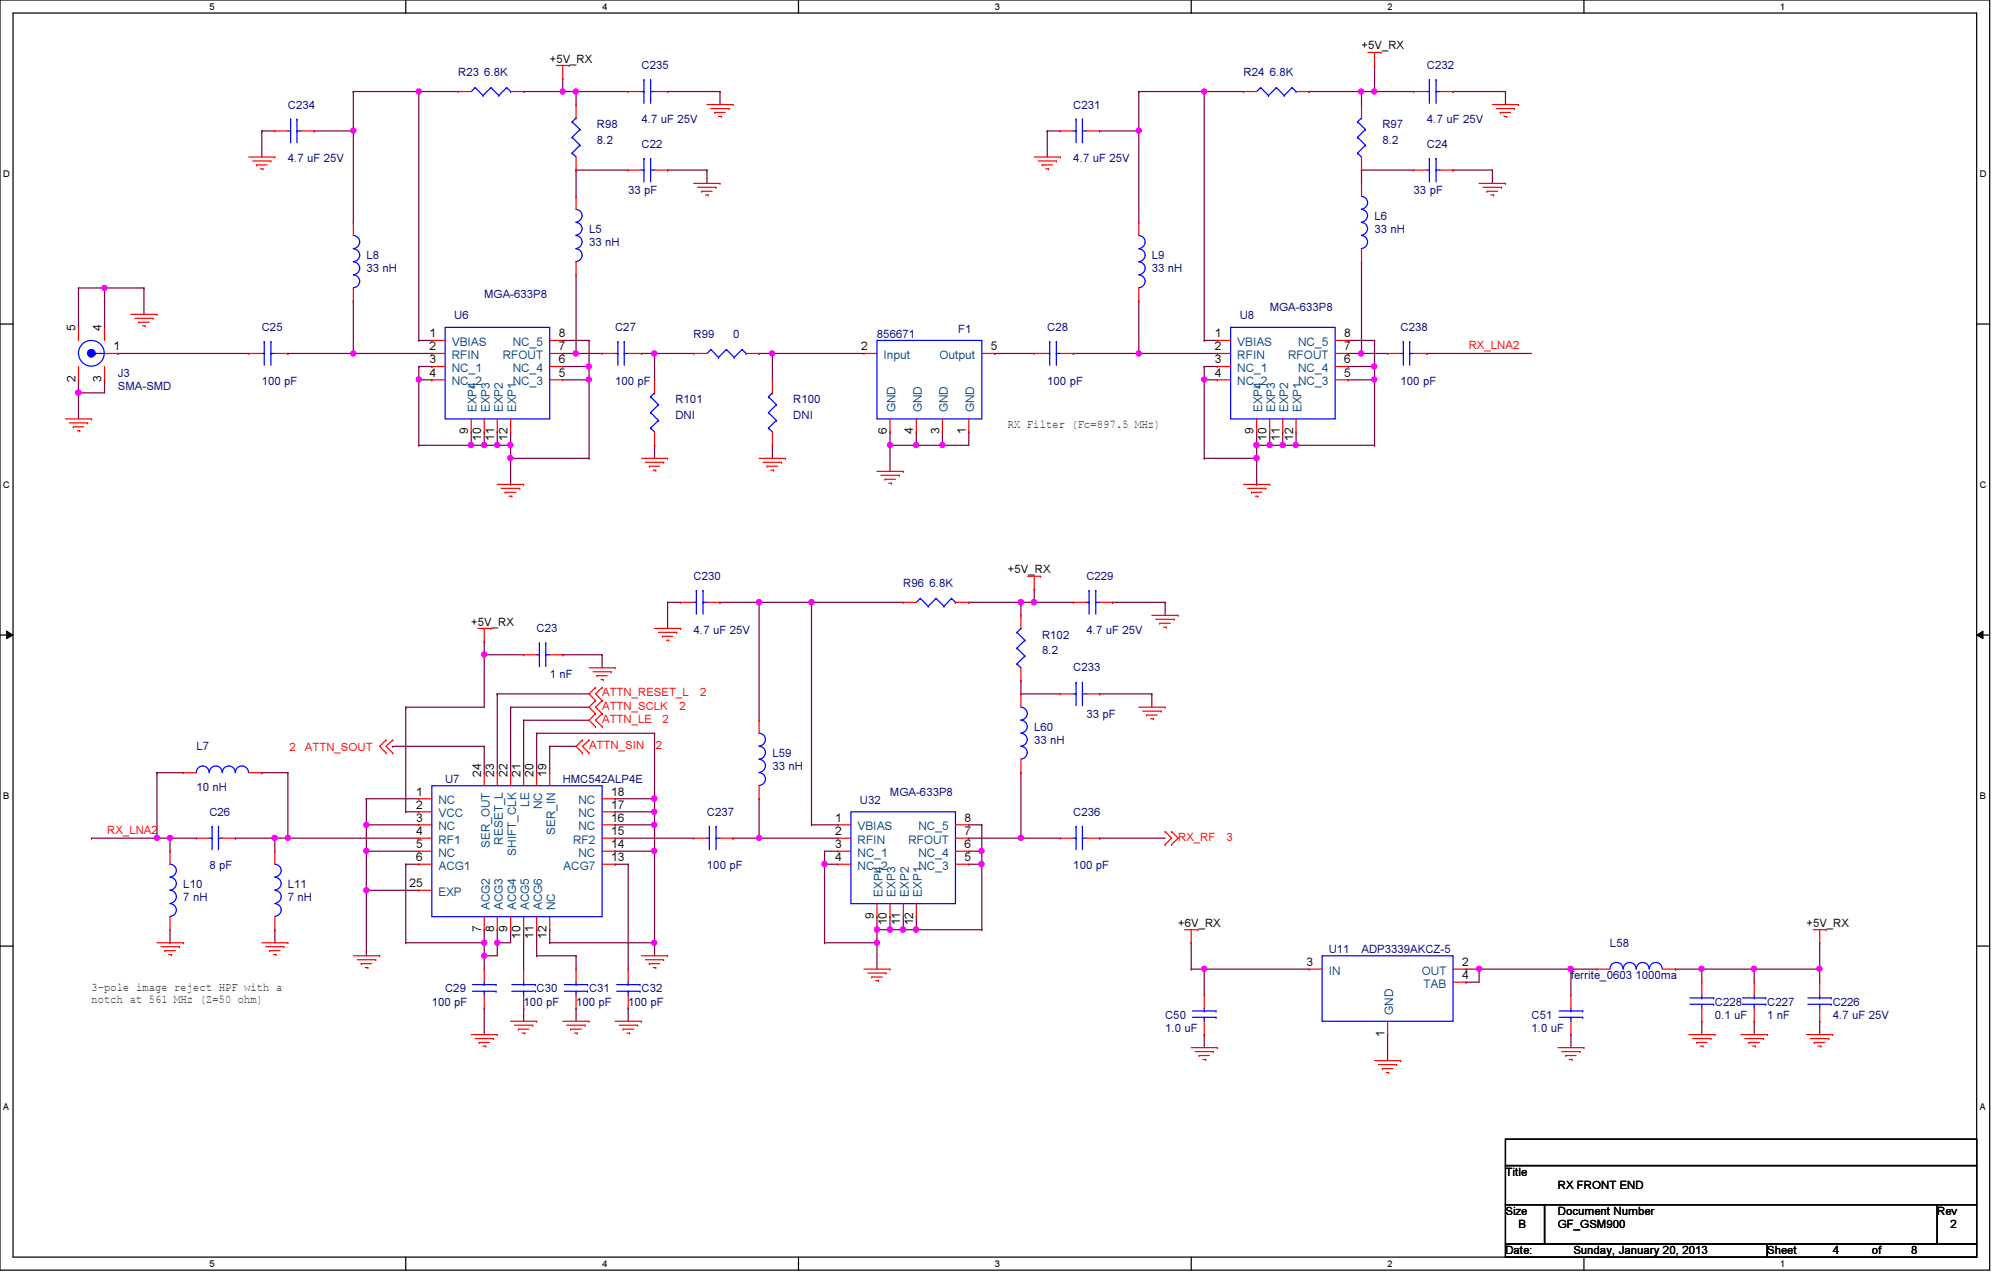
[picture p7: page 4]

RX Filter (Fc=897.5 MHz)

3-pole image reject HPF with a
notch at 561 MHz (Z=50 ohm)

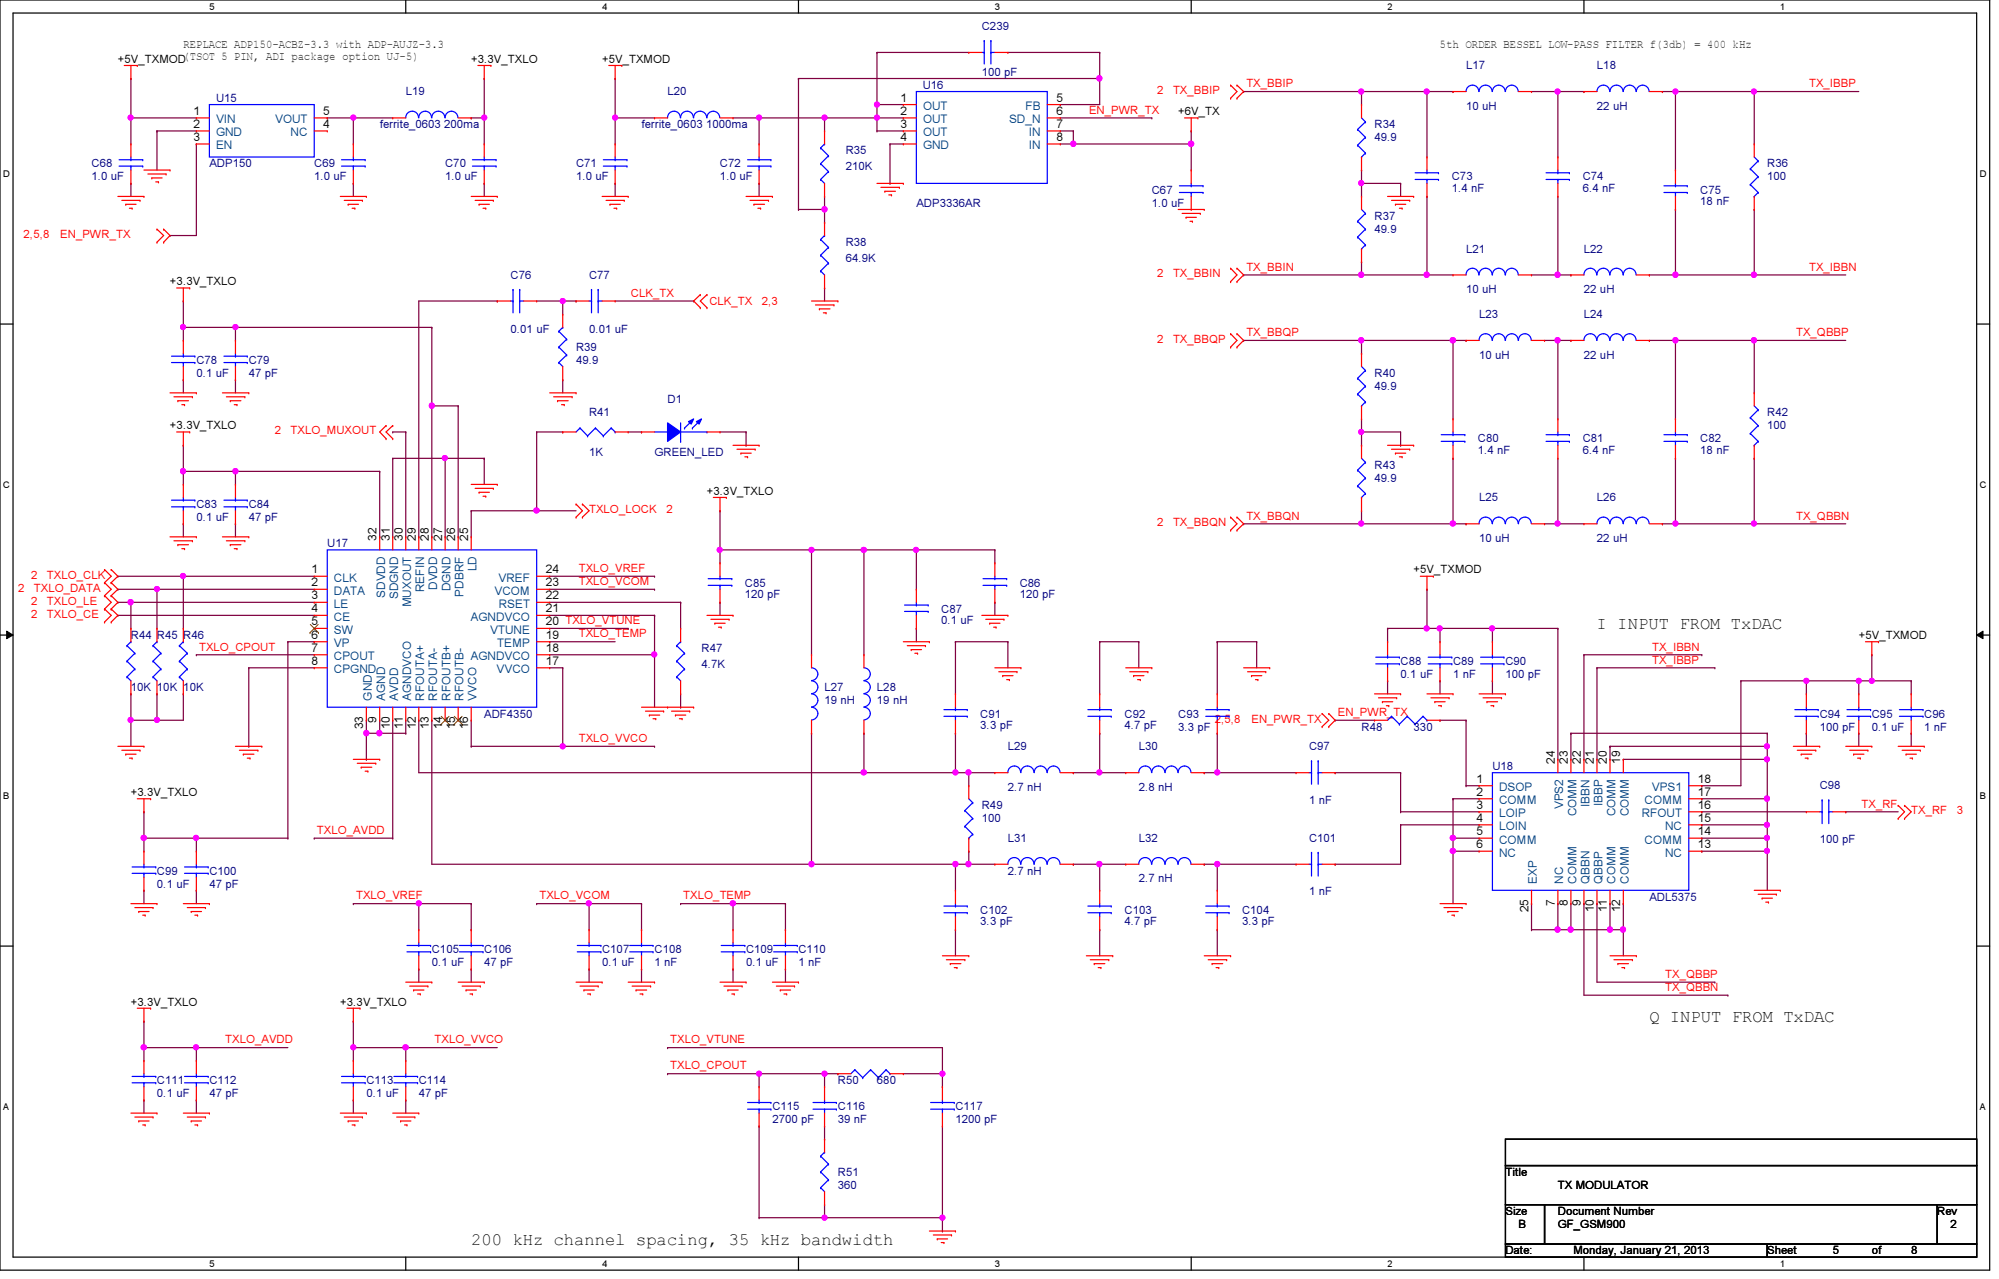
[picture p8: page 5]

(TSOT 5 PIN, ADI package option UJ-5)

200 kHz channel spacing, 35 kHz bandwidth

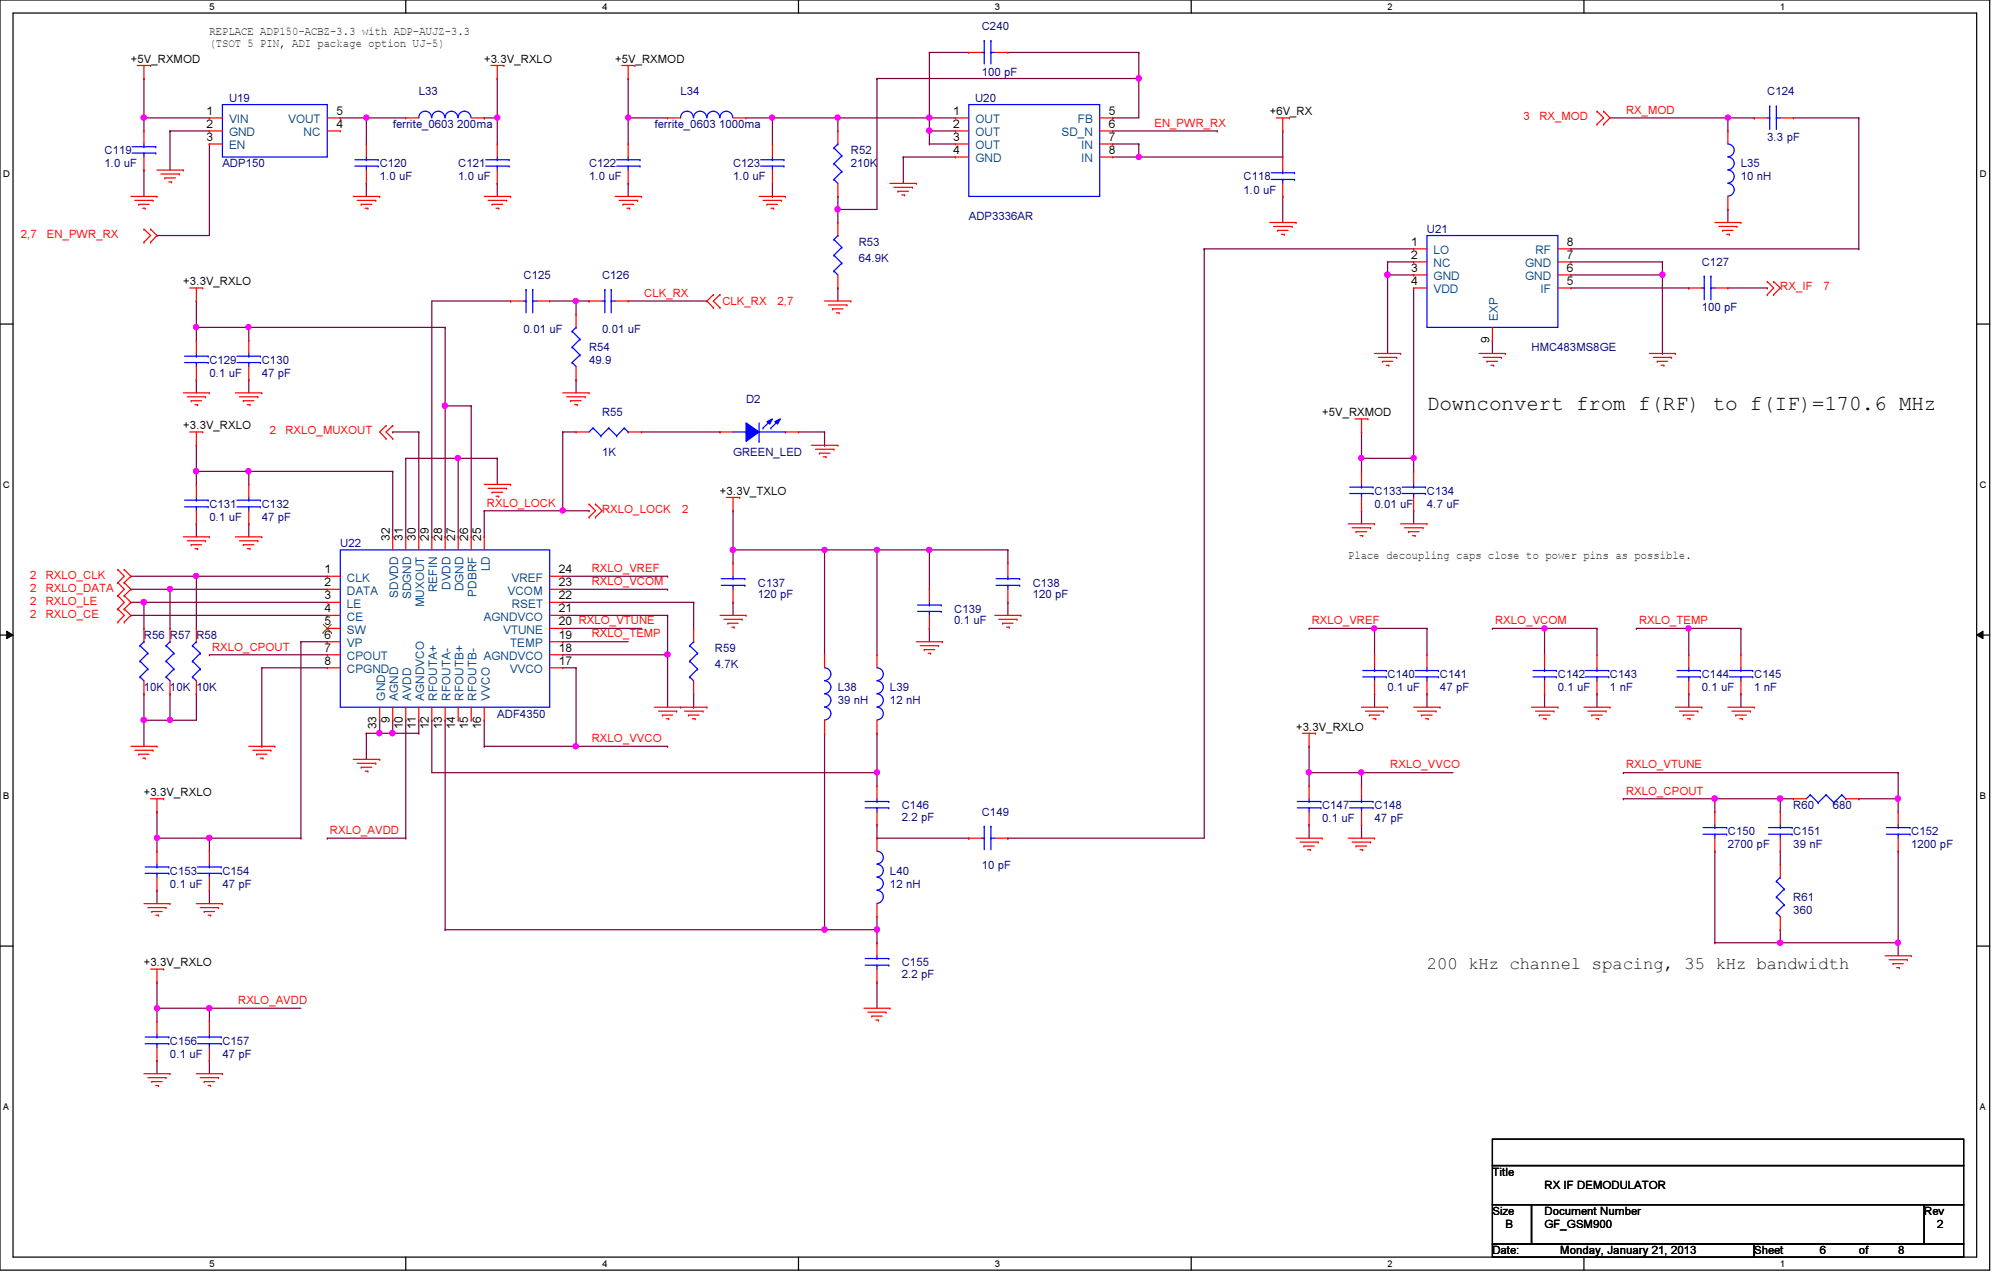
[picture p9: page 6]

REPLACE ADP150-ACBZ-3.3 with ADP-AUJZ-3.3
(TSOT 5 PIN, ADI package option UJ-5)

Downconvert from f(RF) to f(IF)=170.6 MHz

Place decoupling caps close to power pins as possible.

200 kHz channel spacing, 35 kHz bandwidth

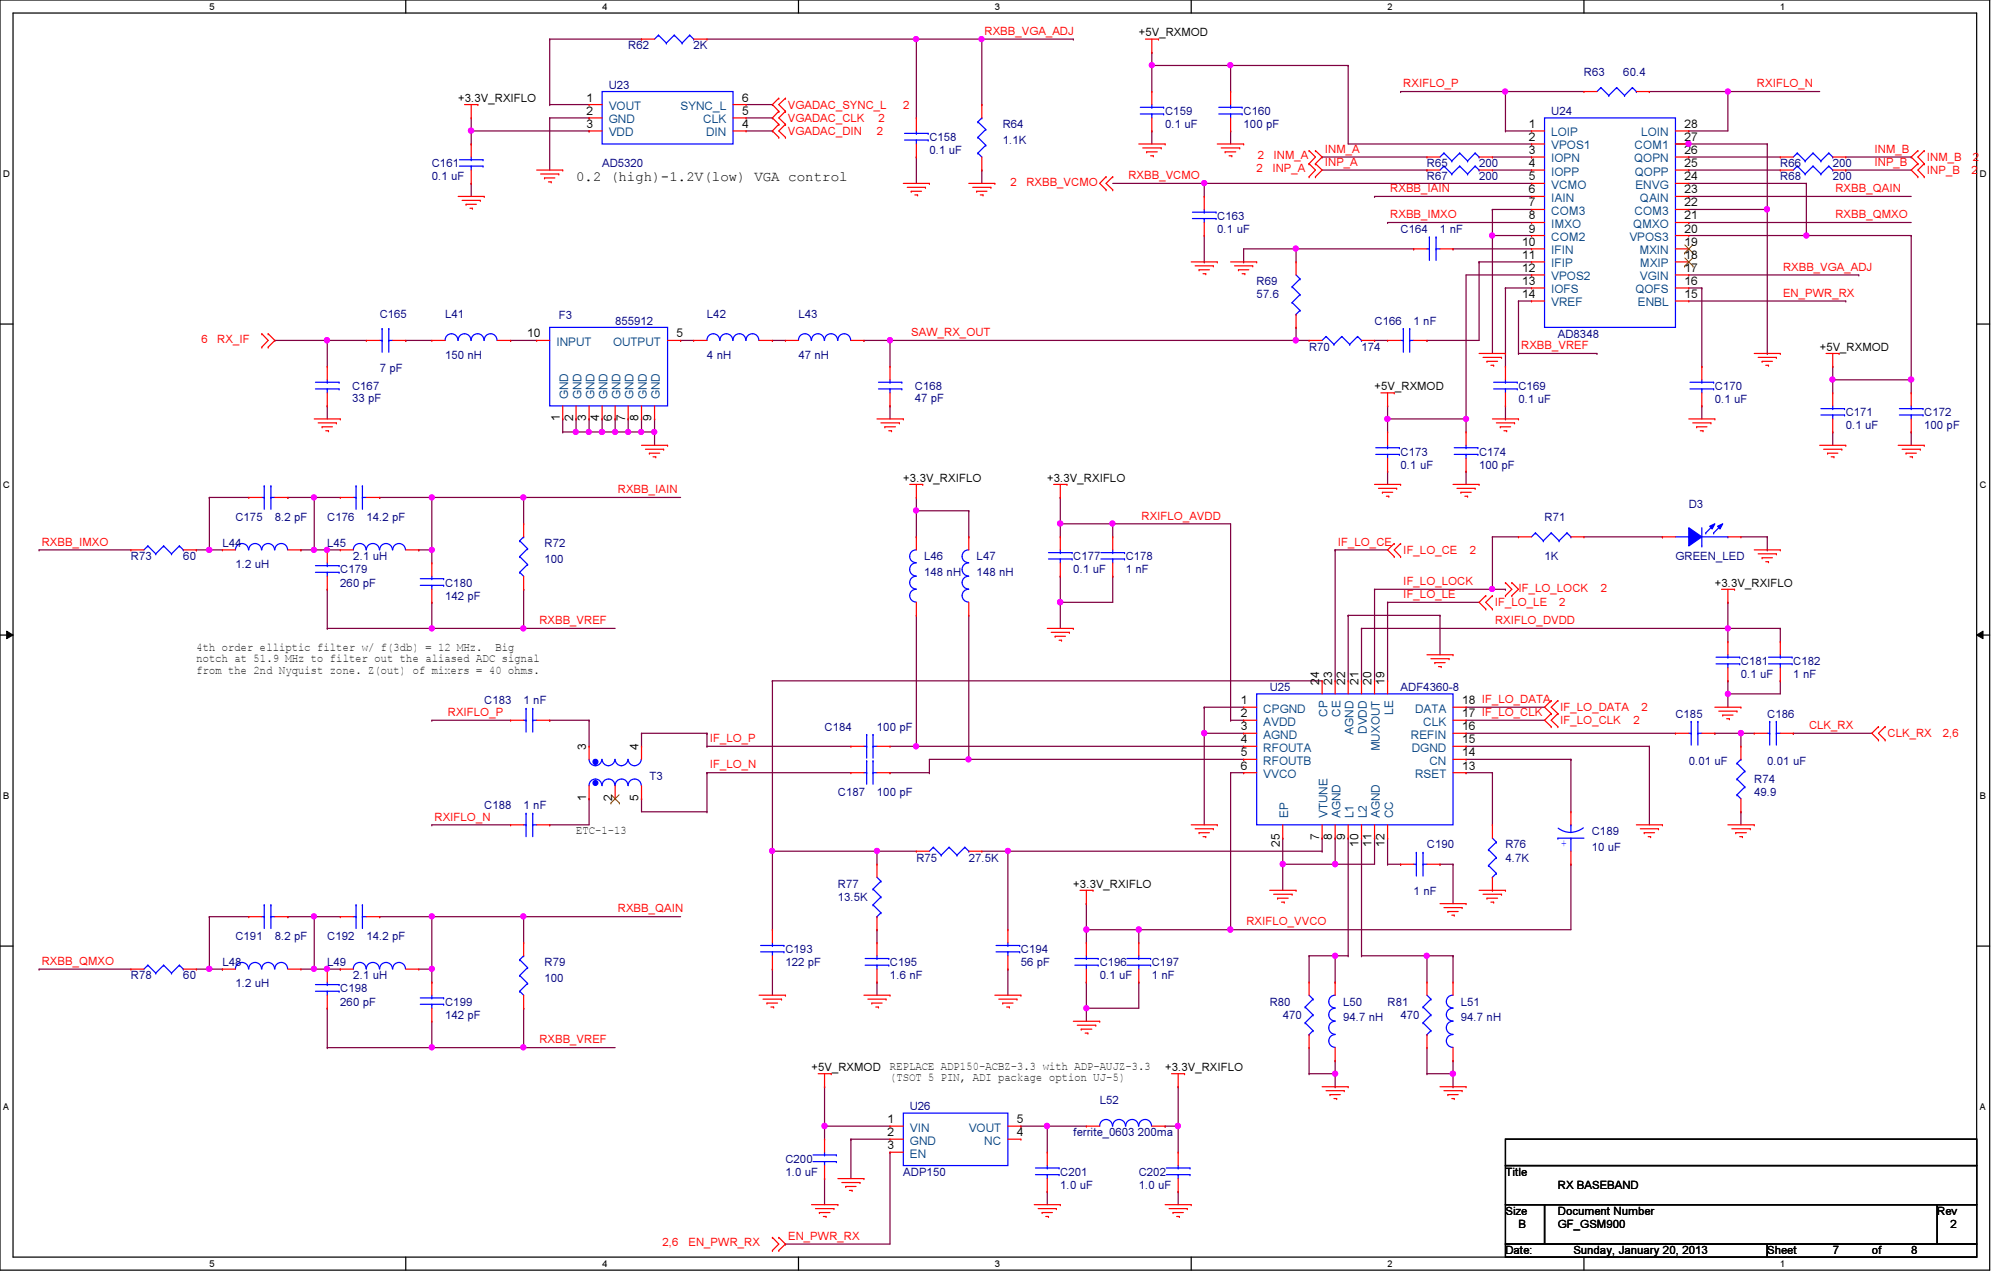
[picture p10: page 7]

0.2 (high)-1.2V(low) VGA control

4th order elliptic filter w/ f(3db) = 12 MHz. Big
notch at 51.9 MHz to filter out the aliased ADC signal
from the 2nd Nyquist zone. Z(out) of mixers = 40 ohms.

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

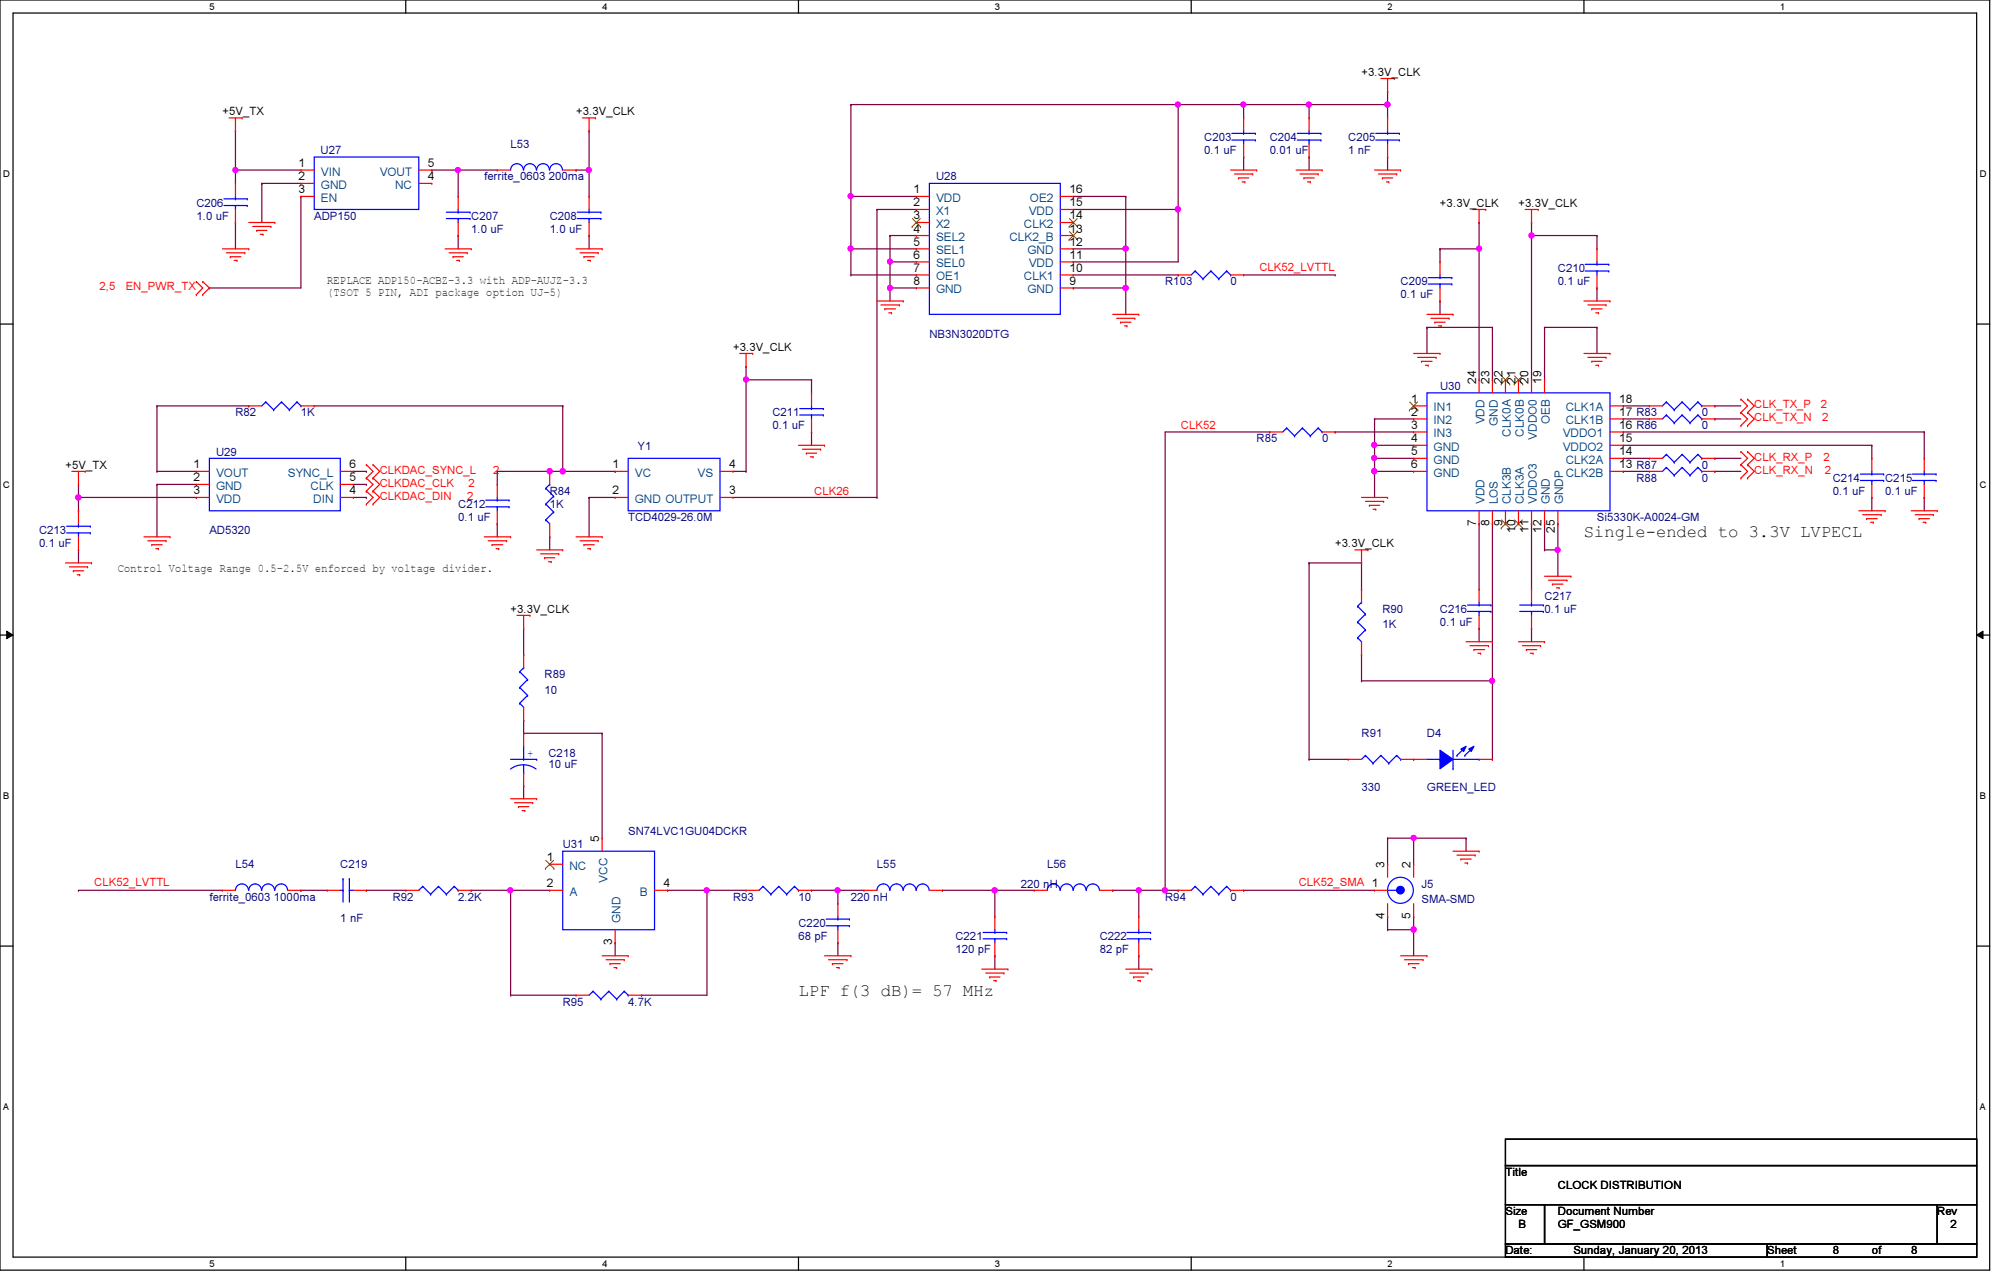
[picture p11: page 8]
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

Single-ended to 3.3V LVPECL

Control Voltage Range 0.5-2.5V enforced by voltage divider.

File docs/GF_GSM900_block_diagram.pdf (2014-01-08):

# Close-Haul GAPFiller GSM 900 USRP-compatible RF daughtercard

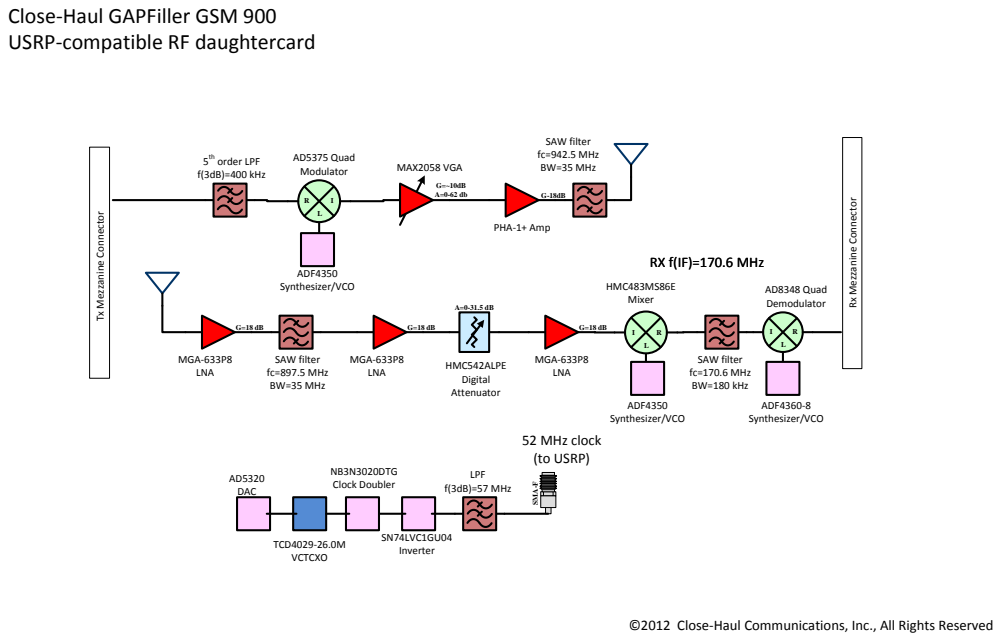
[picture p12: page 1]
ezzanin; ector; order LPF f(3dB)=400 kHz; SAW filter fc=942.5 MHz BW=35 MHz; SAW filter fc=897.5 MHz BW=35 MHz; SAW filter fc=170.6 MHz BW=180 kHz; AD5375 Quad Modulator; ADF4350 Synthesizer/VCO; ADF4360-8 Synthesizer/VCO; MAX2058 VGA; PHA-1+ Amp; MGA-633P8 LNA; MGA-633P8 LNA HMC542ALPE Digital Attenuator; HMC483MS86E Mixer; AD8348 Quad Demodulator; TCD4029-26.0M VCTCXO; AD5320 DAC; NB3N3020DTG Clock Doubler; SN74LVC1GU04 Inverter; LPF f(3dB)=57 MHz; 52 MHz clock (to USRP)

RX f(IF)=170.6 MHz

©2012 Close-Haul Communications, Inc., All Rights Reserved
